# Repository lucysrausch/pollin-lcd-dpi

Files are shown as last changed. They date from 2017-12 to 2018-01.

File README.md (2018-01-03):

#### Installation

1. Download Raspbian Stretch Lite from
https://www.raspberrypi.org/downloads/raspbian/

2. Copy to SD card (> 4GB)

    > dd if=/home/niklas/Downloads/2017-11-29-raspbian-stretch-lite.img | pv | dd of=/dev/sdb<br/>
    > sync

3. Plug SD card in your Pi and power it up. Wait for a few minutes.

4. Plug the SD card back to your PC. Mount the boot partition and edit the "config.txt". Go to the bottom and add:

    >dtoverlay=dwc2as
    >
    >#Overscan Information.<br/>
    >#overscan_left=-32<br/>
    >#overscan_right=-32<br/>
    >overscan_top=10<br/>
    >#overscan_bottom=-32<br/>
    >framebuffer_width=960<br/>
    >framebuffer_height=160<br/>
    >
    >#Enable the lcd, enable custom display sizes with CVT, set as the default >output.<br/>
    >enable_dpi_lcd=1<br/>
    >dpi_group=2<br/>
    >dpi_mode=87 # Hdmi CVT<br/>
    >display_default_lcd=1<br/>
    >
    >dpi_output_format=458773<br/>
    >hdmi_timings=960 0 40 48 88 160 0 13 3 32 0 0 0 60 0 32000000 3<br/>

5. Save the config.txt file as plain text and then open "cmdline.txt".
After rootwait (the last word on the first line) add a space and then
    >modules-load=dwc2,g_ether

6. Enable SSH. Create a empty file named "ssh" on the boot partition:

    >echo "" > /boot/ssh

7. Plug in your Pi with a USB Micro cable. Make sure to use the "USB" plug.

8. SSH to your Pi, connected as a network device:
    >ssh pi@raspberrypi.local

9. Expand the filesystem using the raspi tool
    >sudo raspi-config

10. On your Pi, install and download few tools. Make sure to share internet with your Pi:
    >sudo apt-get install device-tree-compiler<br/>
    >wget https://raw.githubusercontent.com/NiklasFauth/pollin-lcd-dpi/master/pollin-dt-blob.dts

11. Create a device-tree file that enables all the required GPIOs:
    >sudo dtc -I dts -O dtb -o /boot/dt-blob.bin pollin-dt-blob.dts

12. Reboot.

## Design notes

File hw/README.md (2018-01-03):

#### PCB Design
There are no known bugs in this hardware revision.
PCB size is 53mm * 250mm, 1.6mm, 2 Layers.

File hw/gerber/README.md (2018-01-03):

------------------------------------------------------------------------------------------
Gerber File Extension Report For: pcb2.GBR   12/14/2017  9:25:16 PM
------------------------------------------------------------------------------------------

------------------------------------------------------------------------------------------
Layer Extension     Layer Description                      
------------------------------------------------------------------------------------------
.GTL                Top Layer                               
.GBL                Bottom Layer                            
.GPB                Bottom Pad Master                       
.GPT                Top Pad Master                          
.GTO                Top Overlay                             
.GTP                Top Paste                               
.GTS                Top Solder                              
.GBS                Bottom Solder                           
.GBP                Bottom Paste                            
.GBO                Bottom Overlay                          
.GKO                Keep-Out Layer                          
.GM1                Mechanical 1                            
------------------------------------------------------------------------------------------

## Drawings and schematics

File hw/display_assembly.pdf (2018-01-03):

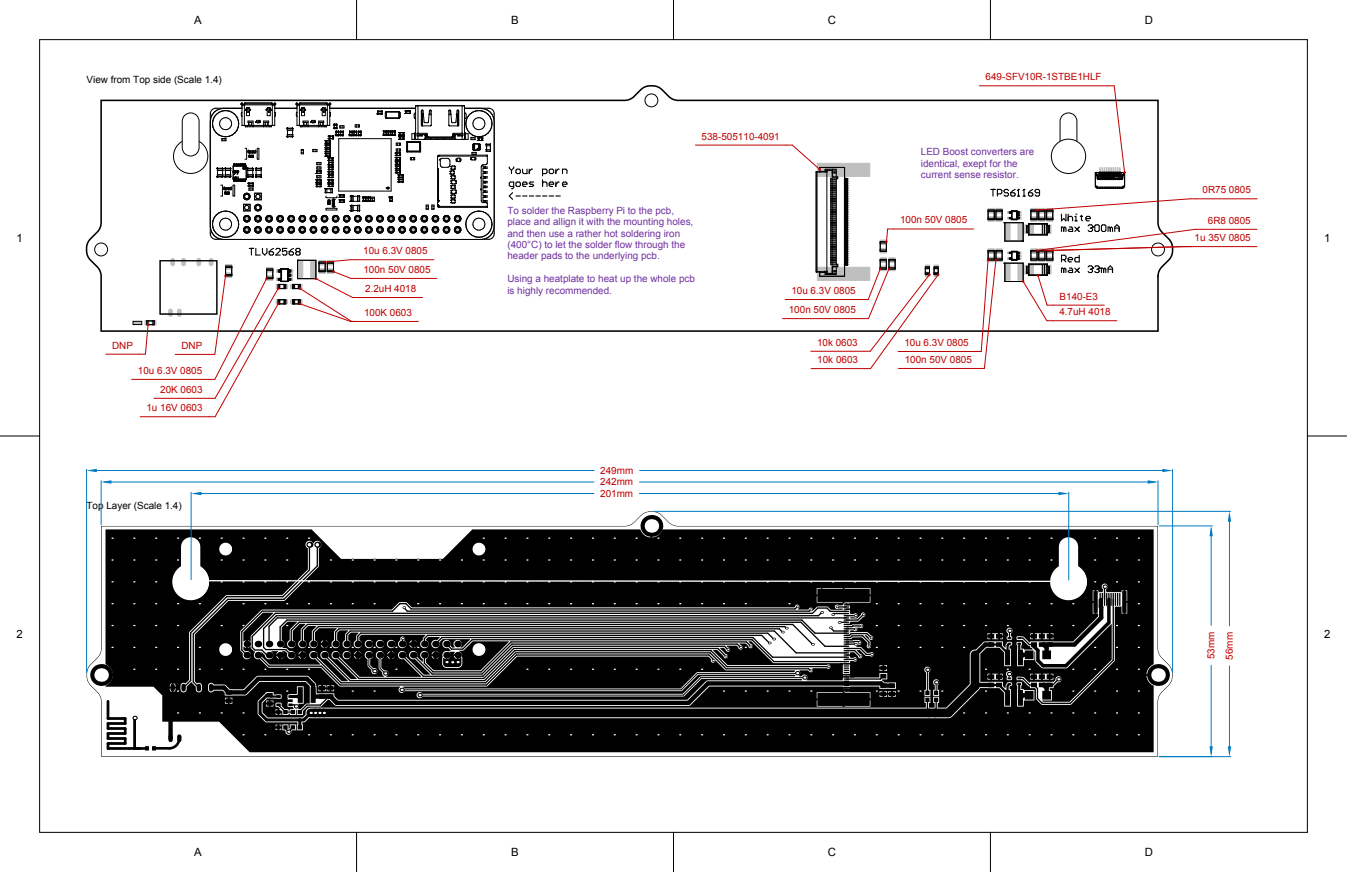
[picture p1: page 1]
649-SFV10R-1STBE1HLF; DNP

View from Top side (Scale 1.4)

LED Boost converters are
identical, exept for the
current sense resistor.

To solder the Raspberry Pi to the pcb,
place and allign it with the mounting holes,
and then use a rather hot soldering iron
(400°C) to let the solder flow through the
header pads to the underlying pcb.

Using a heatplate to heat up the whole pcb
is highly recommended.

Top Layer (Scale 1.4)

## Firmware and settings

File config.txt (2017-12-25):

# For more options and information see
# http://www.raspberrypi.org/documentation/configuration/config-txt.md
# Some settings may impact device functionality. See link above for details

# uncomment if you get no picture on HDMI for a default "safe" mode
#hdmi_safe=1

# uncomment this if your display has a black border of unused pixels visible
# and your display can output without overscan
#disable_overscan=1

# uncomment the following to adjust overscan. Use positive numbers if console
# goes off screen, and negative if there is too much border
#overscan_left=16
#overscan_right=16
#overscan_top=16
#overscan_bottom=16

# uncomment to force a console size. By default it will be display's size minus
# overscan.
#framebuffer_width=1280
#framebuffer_height=720

# uncomment if hdmi display is not detected and composite is being output
#hdmi_force_hotplug=1

# uncomment to force a specific HDMI mode (this will force VGA)
#hdmi_group=1
#hdmi_mode=1

# uncomment to force a HDMI mode rather than DVI. This can make audio work in
# DMT (computer monitor) modes
#hdmi_drive=2

# uncomment to increase signal to HDMI, if you have interference, blanking, or
# no display
#config_hdmi_boost=4

# uncomment for composite PAL
#sdtv_mode=2

#uncomment to overclock the arm. 700 MHz is the default.
#arm_freq=900

# Uncomment some or all of these to enable the optional hardware interfaces
#dtparam=i2c_arm=on
#dtparam=i2s=on
#dtparam=spi=on

# Uncomment this to enable the lirc-rpi module
#dtoverlay=lirc-rpi

# Additional overlays and parameters are documented /boot/overlays/README

# Enable audio (loads snd_bcm2835)
dtparam=audio=on
#core_freq=250
#sdram_freq=450
#over_voltage=2
dtparam=spi=off
dtparam=i2c_arm=off

dtoverlay=dwc2as

#Overscan Information.
#overscan_left=-32
#overscan_right=-32
overscan_top=10
#overscan_bottom=-32
framebuffer_width=960
framebuffer_height=160

#Enable the lcd, enable custom display sizes with CVT, set as the default output.
enable_dpi_lcd=1
dpi_group=2
dpi_mode=87 # Hdmi CVT
display_default_lcd=1

dpi_output_format=458773
hdmi_timings=960 0 40 48 88 160 0 13 3 32 0 0 0 60 0 32000000 3

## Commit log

2017-01-13 ADD: config file
    [config.txt]
2017-12-25 ADD: modified devicetree source for Raspberry Pi Zero W
    [config.txt]
2018-01-03 ADD: hardware desihn files
    [pcb2.GBL, pcb2.GBO, pcb2.GBP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]
